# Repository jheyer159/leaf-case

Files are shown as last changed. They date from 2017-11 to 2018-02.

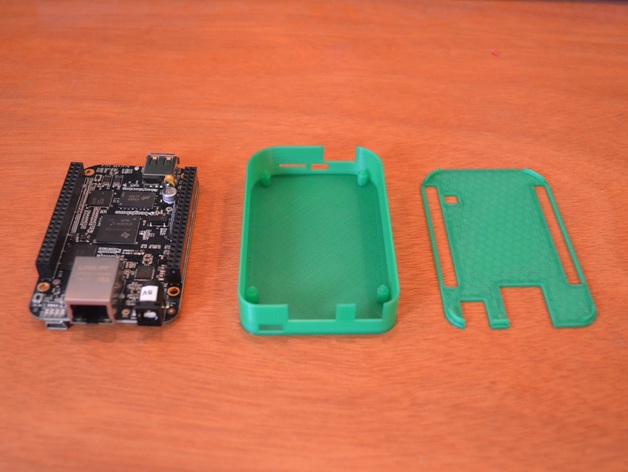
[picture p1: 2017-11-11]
images/BBB_Slim_Parts_View_preview_featured.jpg

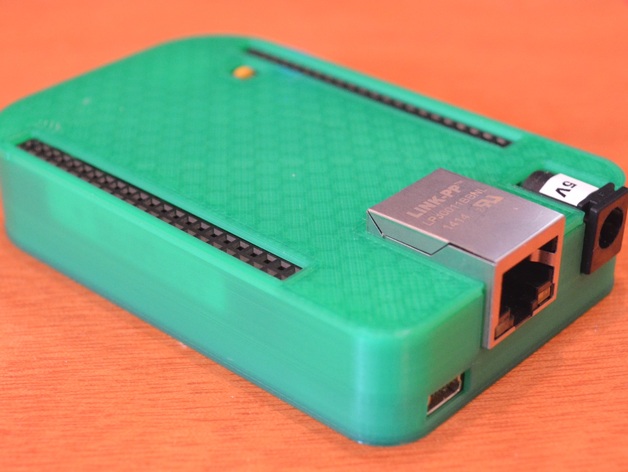
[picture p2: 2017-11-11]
images/BBB_Slim_Overview_2_preview_featured.jpg

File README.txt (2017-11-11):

                   .:                     :,                                          
,:::::::: ::`      :::                   :::                                          
,:::::::: ::`      :::                   :::                                          
.,,:::,,, ::`.:,   ... .. .:,     .:. ..`... ..`   ..   .:,    .. ::  .::,     .:,`   
   ,::    :::::::  ::, :::::::  `:::::::.,:: :::  ::: .::::::  ::::: ::::::  .::::::  
   ,::    :::::::: ::, :::::::: ::::::::.,:: :::  ::: :::,:::, ::::: ::::::, :::::::: 
   ,::    :::  ::: ::, :::  :::`::.  :::.,::  ::,`::`:::   ::: :::  `::,`   :::   ::: 
   ,::    ::.  ::: ::, ::`  :::.::    ::.,::  :::::: ::::::::: ::`   :::::: ::::::::: 
   ,::    ::.  ::: ::, ::`  :::.::    ::.,::  .::::: ::::::::: ::`    ::::::::::::::: 
   ,::    ::.  ::: ::, ::`  ::: ::: `:::.,::   ::::  :::`  ,,, ::`  .::  :::.::.  ,,, 
   ,::    ::.  ::: ::, ::`  ::: ::::::::.,::   ::::   :::::::` ::`   ::::::: :::::::. 
   ,::    ::.  ::: ::, ::`  :::  :::::::`,::    ::.    :::::`  ::`   ::::::   :::::.  
                                ::,  ,::                               ``             
                                ::::::::                                              
                                 ::::::                                               
                                  `,,`

http://www.thingiverse.com/thing:471661
Beaglebone Black Slim Case by Scuttlebot is licensed under the GNU - GPL license.
http://creativecommons.org/licenses/GPL/2.0/

# Summary

******************************************************************   
## NEWS: Version 2 released! See below for details.  
******************************************************************  

## CASE DETAILS  

This is a slim line case for the Beaglebone Black development board that was developed with the following goals in mind:  
-Minimize volume and plastic used  
-Expose all eternal ports   
-Expose pin headers for development  
-Code with OpenSCAD for easy modification  
-Tight tolerances to secure board when moving around
-Include pin header diagram that can print on standard shipping labels  

See instruction section for printing and label details

The OpenSCAD source files are attached and can be used to modify the case with options at the top of the file. The library file is a good reference for board dimensions in other projects.  
*******************************************************  

## UPDATES  

*1-23-15:* Version 2 OpenSCAD files posted  
Cleaned up the OpenSCAD files and posted them to the source files list. The Beaglebone dimension constants were moved to an external library file to help clean up the main code file. If you want to make your own BBB accessory you might find this useful and save yourself a bunch of work!  

*12-30-14:* Version 2 released!  
Updated based on my experience carting the case around in my backpack for three months.  

* Thickened the wall slightly for better rigidity  
* Strengthened the tabs that secure the lid for better grip and to help prevent snapping off during case abuse.  
* Added extra area to the bottom of the board pegs to prevent snapping off after excessive use.  
* Used a better library for creating the rounded corners that should make for smoother slicing  
* Moved all of the dimension constants from the main OpenSCAD file to a library file to help code readability.  

*9-22-14:* Added dimensionally accurate pin header labels!  
Thanks to my amazing wife for creating this. See instructions for info  

# Instructions

*******************************************************  
##3D Printing Information  
The case does not require any external hardware at this time. The case shown was printed on a Lulzbot Taz 4 and sliced with Slic3r using the following settings:  
2 Perimeters  
2 Solid Layers top and bottom  
30% infill  
Green PLA at 190C  
*******************************************************  
##Snug Fit
The board tolerances are tight to securely hold the board in place while carrying around. This works great for the majority of users but in a few cases when a printer slightly over extrudes or is printed with a material that requires large perimeters then the beaglebone may be a bit too snug. Two options are to either reduce perimeter extrusion width or print at 102% scale. Both have been reported to work by different users. 

##Pin Header Label:   
The included label PDF file is made to print on Avery 4"x2" shipping labels that can be found at any office supply or department store. The label spacing is 0.1" to physically match the locations of the pins. Just print, cut, and line up.  
*******************************************************  
##OpenSCAD  
You will need both the base scad file and the library file in the same directory to work. The base scad file has several options at the top to modify what model is generated. The settings and their effects are listed in the comments.  

The scad files are provided open source so feel free to modify and borrow from as you wish. The library file is useful if you would like a pre-created list of all Beaglebone Black dimensions. If you do use my code for other projects a link back or reference is always appreciated but not necessary. I love to see what other can build from my work!

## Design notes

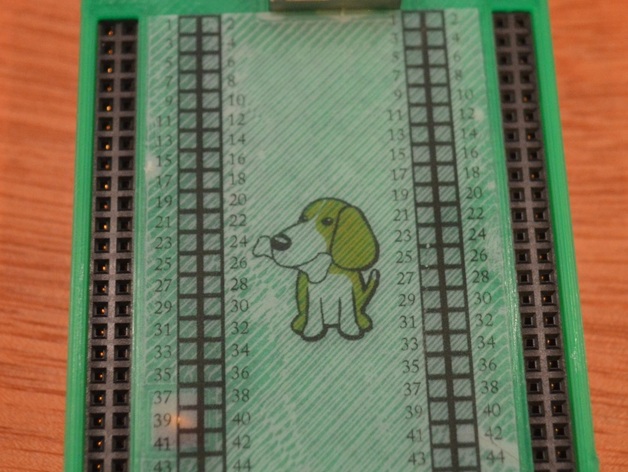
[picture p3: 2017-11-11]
images/BBB_Slim_Pin_Label_preview_featured.jpg

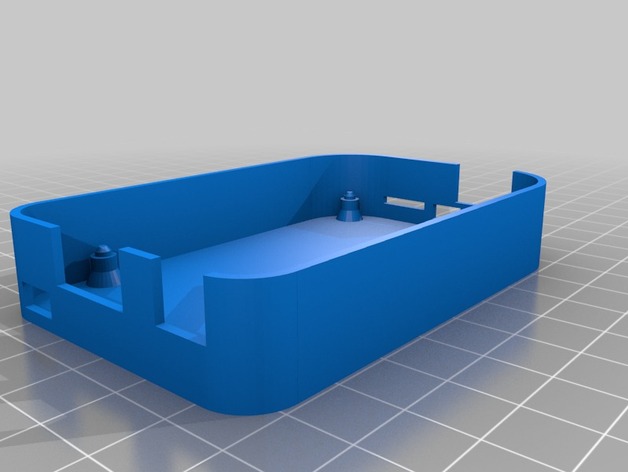
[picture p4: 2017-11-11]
images/BBB_SlimCase_v2_Base_preview_featured.jpg

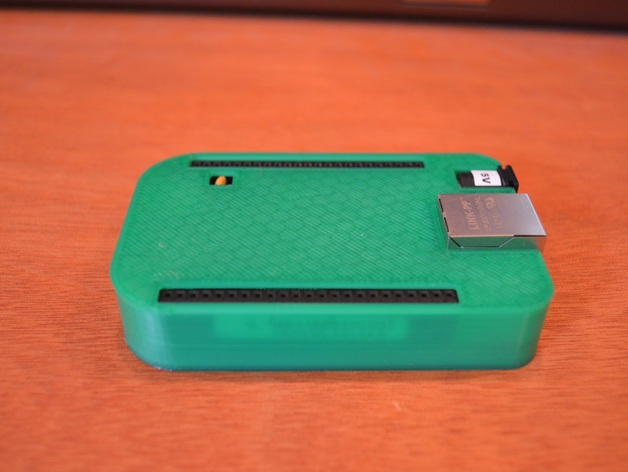
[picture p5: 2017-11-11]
images/BBB_Slim_Side_View_preview_featured.jpg

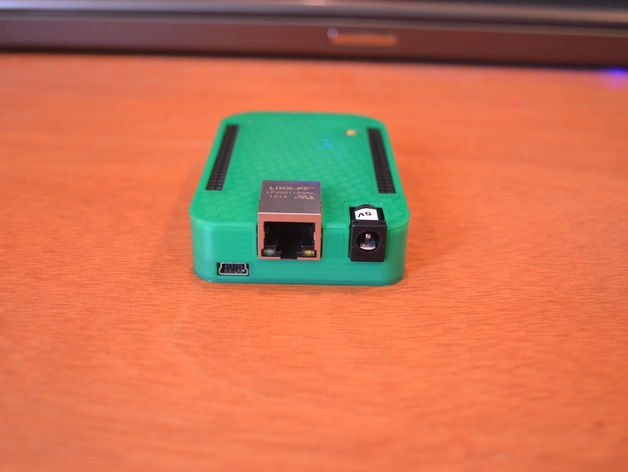
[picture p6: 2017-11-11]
images/BBB_Slim_Front_View_preview_featured.jpg

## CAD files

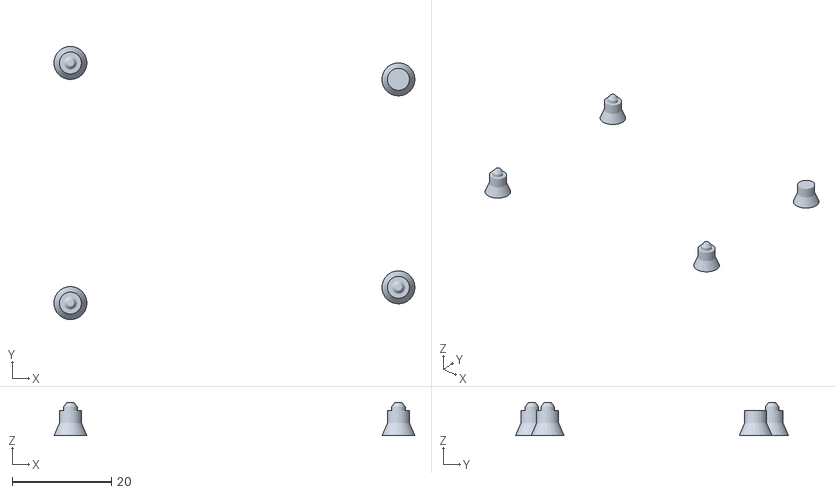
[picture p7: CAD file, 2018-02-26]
files/pegs.stl
72.7 x 55.1 x 6.75

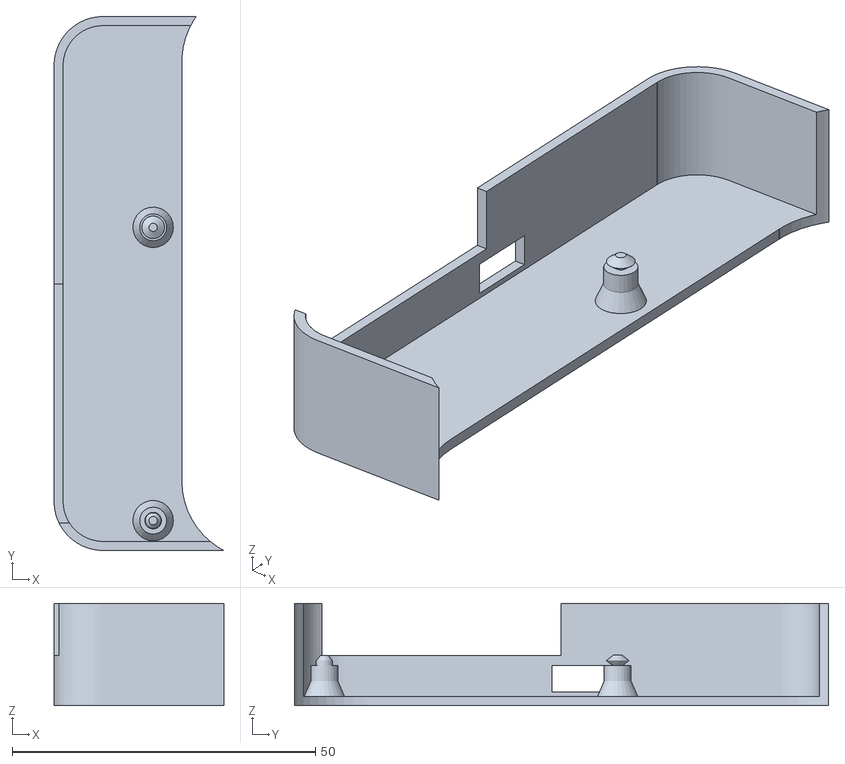
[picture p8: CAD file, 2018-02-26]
files/usb_side.stl
28.0 x 88.1 x 16.9

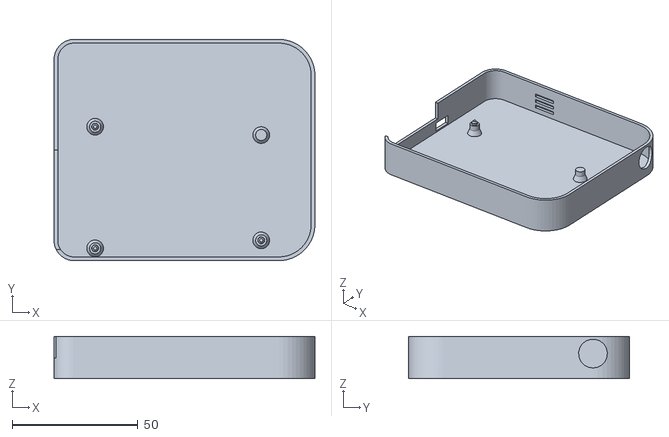
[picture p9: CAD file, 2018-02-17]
files/BBB_SlimCase_v3.stl
103.9 x 88.1 x 16.9

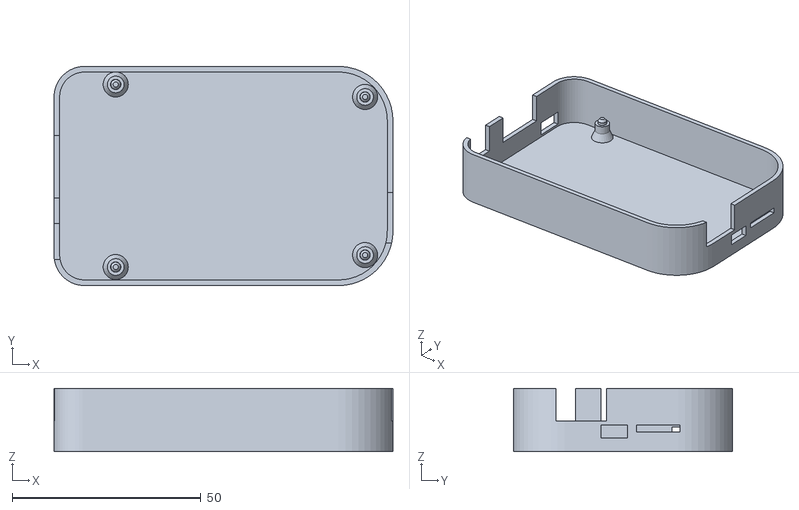
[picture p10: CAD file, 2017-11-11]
files/BBB_SlimCase_v2_Base.stl
89.9 x 58.1 x 16.8

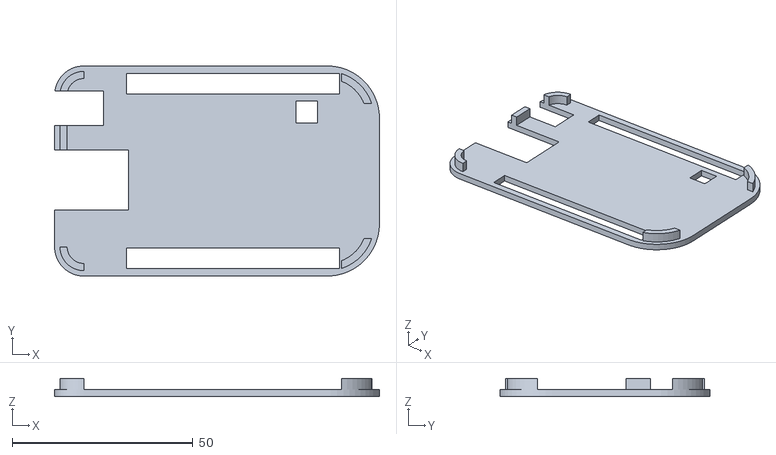
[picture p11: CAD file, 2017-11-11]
files/BBB_SlimCase_v2_Lid.stl
89.9 x 58.1 x 5.00

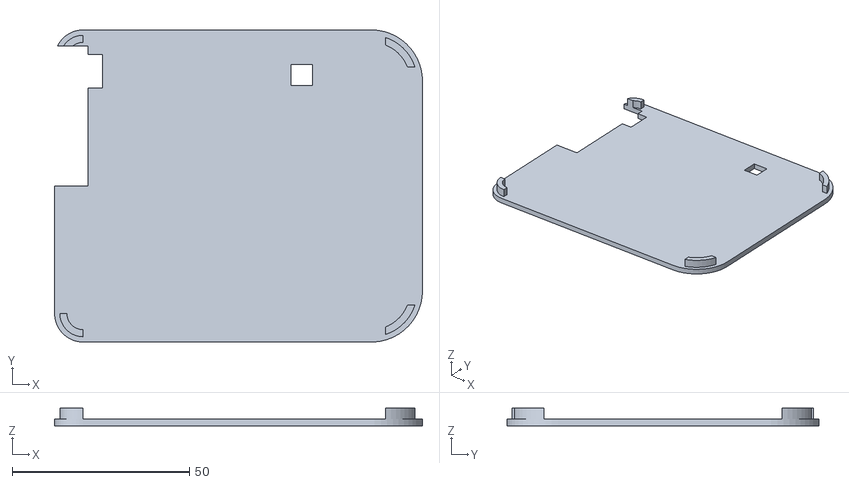
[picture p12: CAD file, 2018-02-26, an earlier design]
files/BBB_SlimCase_v2.stl
103.9 x 88.1 x 5.00

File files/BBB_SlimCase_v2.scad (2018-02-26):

// ******************************************
// Beaglebone Black Slim Case
// By Isaac Hayes
// Copyright 2014
// http://scuttlebots.com
//
// This program is free software; you can redistribute it and/or modify
// it under the terms of the GNU General Public License as published by
// the Free Software Foundation; either version 2 of the License, or
// (at your option) any later version.
//
// This program is distributed in the hope that it will be useful,
// but WITHOUT ANY WARRANTY; without even the implied warranty of
// MERCHANTABILITY or FITNESS FOR A PARTICULAR PURPOSE.  See the
// GNU General Public License for more details.
//
// You should have received a copy of the GNU General Public License along
// with this program; if not, write to the Free Software Foundation, Inc.,
// 51 Franklin Street, Fifth Floor, Boston, MA 02110-1301 USA.
// ******************************************

// ************************************
// Render Options
// ************************************

// RENDER OPTIONS
// Set this variable to output the piece you want
// 0 - No Render
// 1 - Visual Only render
// 2 - Base for STL Export
// 3 - Lid for STL Export

   Render_Options = 3;

// LID OPTIONS
// Set this to select various lid Options
// 0 = Solid
// 1 = Pin Header Cut Outs

   Lid_Options = 0;

// DEV STATION OPTIONS
// Set this to add bottom rails for attachment to the BBB Dev Station Sled accessory
// 0 = Case Only
// 1 = Include rails

	DevRails_Options = 0;

// ************************************
// Include External Libraries
// ************************************

// 
include <BBB_SlimCase_v2_Library.scad>

// ************************************
// Dimensions and Locations Math(s)
// ************************************

// -All dimensions in millimeters
// -Origin at bottom left corner of PCB
// -Ethernet and power jack face left closest to origin
// -X and Y refer to position of lower left corner of compoenent from origin
// -Z refers to distance from top of component to the PCB
// -L and W are Lenght(X) and Width(Y) to specify component size


// ************************************
// Components
// ************************************

module Base()
{
	union() {
	difference() {
		//Outer Shell of Case (Join two cubes together with different corner radii to achieve different size corners on each end)
		translate([-Case_Thickness-Case_Gap, -Case_Thickness-Case_Gap, -Case_Thickness]) {
		union() {
			roundCornersCube(Case_L-Case_LgCurve_R, Case_W, Case_Z, Case_SmCurve_R);
			translate ([Case_SmCurve_R,0,0]) roundCornersCube(Case_L-Case_SmCurve_R, Case_W, Case_Z, Case_LgCurve_R);
		}}
		
		//Hollow Out Inside of Case
		translate([-Case_Gap,-Case_Gap,0]) {
		union() {
			roundCornersCube(CutOut_L-CutOut_LgCurve_R, CutOut_W, CutOut_Z, CutOut_SmCurve_R);
			translate ([CutOut_SmCurve_R,0,0]) roundCornersCube(CutOut_L-CutOut_SmCurve_R, CutOut_W, CutOut_Z, CutOut_LgCurve_R);
		}}
		
		//Components Cutouts

		//Ethernet Jack
		translate([BB_Eth_X-Cmp_Gap-Case_Thickness+0.5, BB_Eth_Y-Cmp_Gap, Case_PCB_Z+BB_Z]) cube([BB_Eth_L+Cmp_Gap2+Case_Thickness+0.5, BB_Eth_W+Cmp_Gap2, BB_Eth_Z+Cmp_Gap]);
		//Power Jack
		/*translate([BB_PJack_X-Cmp_Gap-Case_Thickness+0.5, BB_PJack_Y-Cmp_Gap, Case_PCB_Z+BB_Z]) cube([BB_PJack_L+Cmp_Gap2+Case_Thickness+0.5, BB_PJack_W+Cmp_Gap2, BB_PJack_Z+Cmp_Gap]);*/
		//MICRO USB Port
		translate([BB_USBD_X-Cmp_Gap-Case_Thickness+0.5, BB_USBD_Y-Cmp_Gap, 0.75]) 
            cube([BB_USBD_L+Cmp_Gap2+Case_Thickness+0.5, BB_USBD_W+Cmp_Gap2, BB_USBD_Z+Cmp_Gap]);
        
        //~~// GROVE SIDE //~~//
        //DHT -- OLD(Y AXIS SQUARE)
        //translate([BB_USBH_X-Cmp_Gap+0.5, BB_USBH_Y-Cmp_Gap, BB_USBH_ZZ]) cube([BB_USBH_L+Cmp_Gap2+Case_Thickness+0.5, BB_USBH_W+Cmp_Gap2, BB_USBH_Z+Cmp_Gap]);
		/*translate([BB_USBH_X-Cmp_Gap, BB_USBH_Y-Cmp_Gap, Case_PCB_Z+BB_Z]) cube([BB_USBH_L+Cmp_Gap2+Case_Thickness+0.5, BB_USBH_W+Cmp_Gap2, CutOut_Z+Cmp_Gap]);
		/*translate([BB_USBH_X-Cmp_Gap, BB_USBH_Y-Cmp_Gap, Case_PCB_Z+BB_Z]) cube([BB_USBH_L+Cmp_Gap2+Case_Thickness+0.5, BB_USBH_W+Cmp_Gap2, CutOut_Z]);//BB_USBH_Z+Cmp_Gap]);*/
		//SD Card
        
		//translate([BB_SD_X-Cmp_Gap, BB_SD_Y-Cmp_Gap, Case_PCB_Z-BB_SD_Z]) cube([BB_SD_L+Cmp_Gap2+Case_Thickness+0.5, BB_SD_W+Cmp_Gap2, BB_SD_Z+Cmp_Gap2]);
		//PH
        
                translate([BB_PH_X-Cmp_Gap, BB_PH_Y-Cmp_Gap, Case_PCB_Z-BB_PH_Z]){
            rotate([90,90,90])
            cylinder(h=10, r=5.75, center=true);
        }
        
        

        
        //DHT SLOTS
        
        translate([BB_DHT_X-Cmp_Gap, BB_DHT_Y-Cmp_Gap, Case_PCB_Z-BB_DHT_Z-3]){
           cube([BB_DHT_L+Cmp_Gap2+Case_Thickness+0.5, BB_DHT_W+Cmp_Gap2, BB_DHT_ZH+Cmp_Gap2]);
        }
        translate([BB_DHT_X-Cmp_Gap, BB_DHT_Y-Cmp_Gap, Case_PCB_Z-BB_DHT_Z]){
           cube([BB_DHT_L+Cmp_Gap2+Case_Thickness+0.5, BB_DHT_W+Cmp_Gap2, BB_DHT_ZH+Cmp_Gap2]);
        }
        translate([BB_DHT_X-Cmp_Gap, BB_DHT_Y-Cmp_Gap, Case_PCB_Z-BB_DHT_Z+3]){
           cube([BB_DHT_L+Cmp_Gap2+Case_Thickness+0.5, BB_DHT_W+Cmp_Gap2, BB_DHT_ZH+Cmp_Gap2]);
        }
	}
    
		//Mounting pegs
		translate([BB_Hole1X,BB_Hole1Y,0]) MountingPeg();
		translate([BB_Hole2X,BB_Hole2Y,0]) MountingPeg();
		translate([BB_Hole3X,BB_Hole3Y,0]) MountingPegFlat();
		translate([BB_Hole4X,BB_Hole4Y,0]) MountingPeg();

		//Dev Station rails
		if (DevRails_Options == 1) {
			translate([Case_SmCurve_R-Case_Thickness-Case_Gap,Case_W-Case_Thickness-Case_Gap,-Case_Thickness]) DevRail(DSR_L, DSR_W, DSR_H);
			translate([DSR_L+Case_SmCurve_R-Case_Thickness-Case_Gap,-Case_Thickness-Case_Gap,-Case_Thickness]) rotate([0,0,180]) {
				DevRail(DSR_L, DSR_W, DSR_H);
			}
		}

	}
}

module Lid()
{
	difference() {	
		translate([-Case_Thickness-Case_Gap, -Case_Thickness-Case_Gap, -Case_Thickness]) {
		union() {
			//
			translate([0,0,Case_Z]) roundCornersCube(Case_L-Case_LgCurve_R, Case_W, Lid_Thickness, Case_SmCurve_R);
			translate ([Case_SmCurve_R,0,Case_Z]) roundCornersCube(Case_L-Case_SmCurve_R, Case_W, Lid_Thickness, Case_LgCurve_R);

			//Lid Grips
			translate([Case_Thickness,Case_Thickness,Case_Z-Lid_Grip_Z]) CornerGrip(Lid_Grip_SmR,Lid_Grip_Thickness,Lid_Grip_Z,0,0);
			translate([Case_L-Case_Thickness,Case_Thickness,Case_Z-Lid_Grip_Z]) CornerGrip(Lid_Grip_LgR,Lid_Grip_Thickness,Lid_Grip_Z,90,4);
			translate([Case_L-Case_Thickness,Case_W-Case_Thickness,Case_Z-Lid_Grip_Z]) CornerGrip(Lid_Grip_LgR,Lid_Grip_Thickness,Lid_Grip_Z,180,4);
			translate([Case_Thickness,Case_W-Case_Thickness,Case_Z-Lid_Grip_Z]) CornerGrip(Lid_Grip_SmR,Lid_Grip_Thickness,Lid_Grip_Z,270,0);
			translate([Case_Thickness,BB_PJack_Y+Case_Thickness+Case_Gap,Case_Z-Lid_Grip_Z]) cube([Lid_Grip_Thickness, BB_Eth_Y-BB_PJack_Y, Lid_Grip_Z]);
		}}

		//Component Cutouts
		
		//Ethernet Jack
		translate([BB_Eth_X-Cmp_Gap-1.25, BB_Eth_Y-Cmp_Gap, Case_PCB_Z+BB_Z]) cube([BB_Eth_L+Cmp_Gap2+1.25, BB_Eth_W+Cmp_Gap2, BB_Eth_Z+Cmp_Gap]);
		//Power Jack
		translate([BB_PJack_X-Cmp_Gap-1.25, BB_PJack_Y-Cmp_Gap, Case_PCB_Z+BB_Z]) cube([BB_PJack_L+Cmp_Gap2+1.25, BB_PJack_W+Cmp_Gap2, BB_PJack_Z+Cmp_Gap]);
		//Pin Headers
		if (Lid_Options == 1) {
			translate([BB_P8_X-Cmp_Gap, BB_P8_Y-Cmp_Gap, 0]) cube([BB_P8_L+Cmp_Gap2, BB_P8_W +Cmp_Gap2, 75]);
			translate([BB_P9_X-Cmp_Gap, BB_P9_Y-Cmp_Gap, 0]) cube([BB_P9_L+Cmp_Gap2, BB_P9_W +Cmp_Gap2, 75]);
		}
		//Capacitor
		translate([BB_Cap_X, BB_Cap_Y, Case_PCB_Z+BB_Z]) cube([BB_Cap_L, BB_Cap_W, BB_Cap_Z]);

		
	}
}

module MountingPeg()
{
	union() {
		cylinder(h=Case_PCB_Z, d=BB_Hole_OD, $fn=25);
		cylinder(h=Case_PCB_Z/2, d1=BB_Hole_OD*1.5, d2=BB_Hole_OD, $fn=25);
		translate([0,0,Case_PCB_Z-0.1]) cylinder(h=BB_Z/2+0.1,d=BB_Hole_ID, $fn=25);
		translate([0,0,Case_PCB_Z+BB_Z/2-0.1]) cylinder(h=BB_Z/2+0.1,d1=BB_Hole_ID, d2=BB_Hole_ID/2, $fn=25);
	}
}

module MountingPegFlat()
{
	union() {
		cylinder(h=Case_PCB_Z, d=BB_Hole_OD, $fn=25);
		cylinder(h=Case_PCB_Z/2, d1=BB_Hole_OD*1.5, d2=BB_Hole_OD, $fn=25);
		//translate([0,0,Case_PCB_Z-0.1]) cylinder(h=BB_Z/2+0.1,d=BB_Hole_ID, $fn=25);
		//translate([0,0,Case_PCB_Z+BB_Z/2-0.1]) cylinder(h=BB_Z/2+0.1,d1=BB_Hole_ID, d2=BB_Hole_ID/2, $fn=25);
	}
}

module CornerGrip(R,T,Z,D,CutOff)
{
	rotate([0,0,D]) {
		difference() {
			translate([R,R,0]) cylinder(r=R, h=Z, $fn=50);
			translate([R,R,0]) cylinder(r=R-T, h=Z, $fn=50);
			translate([R-CutOff,0,0]) cube([R*2+CutOff,R*2+CutOff,Z]);
			translate([0,R-CutOff,0]) cube([R*2+CutOff,R*2+CutOff,Z]);
		}
	}
}

module DevRail(X, Y, Z)
{
	SZ = Z * cos(45);
	union() {
		cube([X,Y,Z]);
		translate([0,Y,0]) rotate([45,0,0]) cube([X,SZ,SZ]);
	}
}

// ************************************
// Output Renders
// ************************************

color("Green"){
	render(convexity=4) {
		if (Render_Options == 1) {
			Base();
			translate([0,0,2]) Lid();
		}
		if (Render_Options == 2) {
			Base();
		}
		if (Render_Options == 3) {
			rotate([180,0,0]) translate([-Case_L/2,-Case_W/2,-Case_Z-Case_Thickness]) Lid();
		}
	}
}

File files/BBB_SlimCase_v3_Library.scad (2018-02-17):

// ******************************************
// Beaglebone Black Slim Case Library
// Functions and Constants
// By Isaac Hayes
// Copyright 2014
// http://scuttlebots.com
//
// This program is free software; you can redistribute it and/or modify
// it under the terms of the GNU General Public License as published by
// the Free Software Foundation; either version 2 of the License, or
// (at your option) any later version.
//
// This program is distributed in the hope that it will be useful,
// but WITHOUT ANY WARRANTY; without even the implied warranty of
// MERCHANTABILITY or FITNESS FOR A PARTICULAR PURPOSE.  See the
// GNU General Public License for more details.
//
// You should have received a copy of the GNU General Public License along
// with this program; if not, write to the Free Software Foundation, Inc.,
// 51 Franklin Street, Fifth Floor, Boston, MA 02110-1301 USA.
// ******************************************

// ************************************
// Dimensions and Locations Math(s)
// ************************************

// -All dimensions in millimeters
// -Origin at bottom left corner of PCB
// -Ethernet and power jack face left closest to origin
// -X and Y refer to position of lower left corner of compoenent from origin
// -Z refers to distance from top of component to the PCB
// -L and W are Lenght(X) and Width(Y) to specify component size

//Board Dimensions
BB_L = 100.36;
BB_W = 84.61;
BB_Z = 1.65;
BB_SmCurve_R = 6.35;
BB_LgCurve_R = 12.70;

//Mounting Hole Locations (Clockwise from Bottom)
BB_Hole1X = 14.61;
BB_Hole1Y = 3.18;

BB_Hole2X = 14.61;
BB_Hole2Y = BB_Hole1Y + 48.39;

BB_Hole3X = BB_Hole1X + 66.10;
BB_Hole3Y = 6.35 + 41.91;

BB_Hole4X = BB_Hole1X + 66.10;
BB_Hole4Y = 6.35;

BB_Hole_ID = 2.75;
BB_Hole_OD = 4.45;

//Pin Headers
BB_P9_X = 18.415;
BB_P9_Y = 0.635;
BB_P9_Z = 8.60;
BB_P9_L = 58.42;
BB_P9_W = 5.08;

BB_P8_X = 18.415;
BB_P8_Y = 48.895;
BB_P8_Z = 8.60;
BB_P8_L = 58.42;
BB_P8_W = 5.08;

//Capacitor
BB_Cap_X = 65.00;
BB_Cap_Y = 8.00;
BB_Cap_Z = 11.00;
BB_Cap_L = 6.00;
BB_Cap_W = 6.00;

//Power jack
BB_PJack_X = -2.54;
BB_PJack_Y = 5.461;
BB_PJack_Z = 10.75;
BB_PJack_L = 14.15;
BB_PJack_W = 9.00;

//4 USB
BB_Eth_X = -2.54;    //Default was -2.54
BB_Eth_Y = 3;        //Default was 5
BB_Eth_Z = 13.33;    // Default 13.33
BB_Eth_L = 10;       // Default was 10 (Moves Opening Up or Down)
BB_Eth_W = 39;       // Default was 31 (Moves Length Towards PowerPlugin Hole)

//DHT
BB_DHT_X = BB_L - 75;
BB_DHT_Y = 84.59 + 0.1;
BB_DHT_Z = -0.5;
BB_DHT_L = 8.50;
BB_DHT_W = 6.55;
BB_DHT_ZH = 1;

//USB MINI POWER
BB_USBD_X = -0.635;        //Default -0.635
BB_USBD_Y = 41;            //Default 37
BB_USBD_Z = 4.1;
BB_USBD_L = 8;           //Def 6.91
BB_USBD_W = 9;          //Def 7.747

//PH
BB_PH_X = BB_L + 0;  //27.50
BB_PH_Y = 72;
BB_PH_Z = -3.4;
BB_PH_L = 7.50;
BB_PH_W = 6.55;

//MicroSD Card Port (Slot only)
BB_SD_X = BB_L - 14.90;
BB_SD_Y = 30.607 + 0.5;
BB_SD_Z = 1.75 - 0.5;
BB_SD_L = 14.90;
BB_SD_W = 11.05;

//CASE DIMENSIONS
//Outer Shell
Case_Thickness = 1.50;     //Wall Thickness
Case_Gap = 0.25;  //Gap between case walls and board
Case_L = BB_L + Case_Thickness*2 + Case_Gap*2;
Case_W = BB_W + Case_Thickness*2 + Case_Gap*2;
Case_SmCurve_R = BB_SmCurve_R + Case_Thickness + Case_Gap;
Case_LgCurve_R = BB_LgCurve_R + Case_Thickness + Case_Gap;
Case_PCB_Z = BB_USBD_Z + 1.00;      //Height PCB is suspended above case floor
Case_Z = Case_Thickness + Case_PCB_Z + BB_Z + BB_P9_Z;      //Total height of case
Cmp_Gap = 0.25;      //Gap around components
Cmp_Gap2 = Cmp_Gap*2;   //Gap around components times two

//Shell hollow inside dimensions
CutOut_L = BB_L + Case_Gap*2;
CutOut_W = BB_W + Case_Gap*2;
CutOut_SmCurve_R = BB_SmCurve_R + Case_Gap;
CutOut_LgCurve_R = BB_LgCurve_R + Case_Gap;
CutOut_Z = Case_Z - Case_Thickness;

//Lid Dimensions
Lid_Thickness = 2.00;
Lid_Grip_Thickness = 2.00;
Lid_Grip_Z = 3.00;
Lid_Grip_SmR = Case_SmCurve_R - Case_Thickness;
Lid_Grip_LgR = Case_LgCurve_R - Case_Thickness;

//Dev Station Rail Dimensions
DSR_L = Case_L - Case_LgCurve_R - Case_SmCurve_R;
DSR_W = 2.0;
DSR_H = 3.0;
DSRH_W = 4.0;

// ************************************
// cornerRoundedCube Module - See source below
// ************************************

// http://codeviewer.org/view/code:1b36 
// Copyright (C) 2011 Sergio Vilches
// This program is free software: you can redistribute it and/or modify it under the terms of the GNU General Public License as published by the Free Software Foundation, either version 3 of the License, or (at your option) any later version.
// This program is distributed in the hope that it will be useful, but WITHOUT ANY WARRANTY; without even the implied warranty of MERCHANTABILITY or FITNESS FOR A PARTICULAR PURPOSE. See the GNU General Public License for more details. You should have received a copy of the GNU General Public License along with this program. If not, see <http://www.gnu.org/licenses/>.
// Contact: s.vilches.e@gmail.com


//     ----------------------------------------------------------- 
//                  Round Corners Cube (Extruded)                
//       roundCornersCube(x,y,z,r) Where:                        
//          - x = Xdir width                                     
//          - y = Ydir width                                     
//          - z = Height of the cube                             
//          - r = Rounding radious                               
                                                              
//       Example: roundCornerCube(10,10,2,1);                    
//      *Some times it's needed to use F6 to see good results!   
//  	 ----------------------------------------------------------- 

// Code was modified to not use centered cubes - Isaac


module createMeniscus(h,radius) // This module creates the shape that needs to be substracted from a cube to make its corners rounded.
difference(){        //This shape is basicly the difference between a quarter of cylinder and a cube
   translate([radius/2+0.1,radius/2+0.1,0]){
      cube([radius+0.2,radius+0.1,h+0.2],center=true);         // All that 0.x numbers are to avoid "ghost boundaries" when substracting
   }

   cylinder(h=h+0.2,r=radius,$fn = 50,center=true);
}


module roundCornersCube(x,y,z,r)  // Now we just substract the shape we have created in the four corners
difference(){
   cube([x,y,z], center=false);

   translate([x-r,y-r,z/2]){  // We move to the first corner (x,y)
      rotate(0){  
         createMeniscus(z,r); // And substract the meniscus
      }
   }
   translate([r,y-r,z/2]){ // To the second corner (-x,y)
      rotate(90){
         createMeniscus(z,r); // But this time we have to rotate the meniscus 90 deg
      }
   }
   translate([r,r,z/2]){ // ... 
      rotate(180){
         createMeniscus(z,r);
      }
   }
   translate([x-r,r,z/2]){
      rotate(270){
         createMeniscus(z,r);
      }
   }
}

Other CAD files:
files/Print_This.stl
files/pegs.scad
files/usb_side.scad
files/BBB_SlimCase_v2_Library.scad
stl/BBB_SlimCase_v2.stl

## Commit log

2017-11-11 Initial commit - removed some ports
    [BBB_SlimCase_v2.scad, BBB_SlimCase_v2_Base.stl, BBB_SlimCase_v2_Library.scad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]
2018-02-07 First print attempt
    [BBB_SlimCase_v2.scad, BBB_SlimCase_v2.stl, BBB_SlimCase_v2_Library.scad]
2018-02-09 Expanded case, added hole for pH, added slots for DHT
    [BBB_SlimCase_v2.scad, BBB_SlimCase_v2_Library.scad]
2018-02-17 Added V3 - USB Hole Larger/Moved - Power Hole Larger/Moved - PH Hole Moved to "Front"
    [BBB_SlimCase_v2.scad, BBB_SlimCase_v3.stl, BBB_SlimCase_v3_Library.scad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]
2018-02-17 Added pegs for testing
    [pegs.scad]
2018-02-17 Added usb side for testing peg fit
    [usb_side.scad]
2018-02-17 Added peg mount grabber
    [usb_side.scad]
2018-02-26 Pushing Sean Changes - Duh
    [BBB_SlimCase_v2.scad, BBB_SlimCase_v2.stl, BBB_SlimCase_v2_Library.scad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]
